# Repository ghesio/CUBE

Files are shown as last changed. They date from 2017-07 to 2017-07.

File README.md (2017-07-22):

# CUBE

## What it is

The CUBE is an IOT device with programmable 6 axis gyroscope/accelerometer, programmable LED lights, IR sensor and Bluetooth Low Energy connection.

It's based on Arduino/Genuino 101, featuring a 3D printed and laser cut shell custom designed.

The challenge of this project was to build a device with programmable functions, capable of working on different contexts, aimed at developers who can develop their own use and improvements for the CUBE.

The main idea is to use this as a music controller: based on gyroscope movements and native applications API, you can control the music you are playing; you can change the song you are listening to by rotating it, you can shuffle the music by shaking it.

It’s possible to use it as a volume controller, like a potentiometer: by rotating it with one side laying on the desk, you can increase or decrease music volume.

It will have an infrared sensor to play/stop music by swiping the hand over it.

## Features

- BLE enable
- Battery powered
- 6-Axis gyroscope
- Distance measure
- 4 LEDs acting as output/information

## Functions:

- Able to recognize rotations (clockwise and counterclockwise only, right now)
- Able to recognize swipes of the hand
- Able to recognize the heading of the cube: you can get the angle of the CUBE
- Able to recognize on which side the CUBE is on

### BOM  

- 1 x Arduino/Genuino 101
- 4 x Neopixel LEDs
- 1 x IR emitter
- 1 x IR receiver
- 1 x Switch
- 1 x 9V battery
- Lasercut and printed parts (with the material you prefer)
- Hot glue
- 20 M3 nuts
- 20 M3 1 cm screws
- Vinyl for stickers

On this repo there are also eagle files for doing an (optional) breakout board for building this project.

## BLE Reference

### Mode control, read/write
*uuid: 988dbab9-a657-45fe-80ef-9f9bed761947, read/write*

This service let choose in which mode you want to use the CUBE

0: Stand-by

1: rotation recognition

2: Swipe recognition

3: Potentiometer mode

4: Face recognition

### Rotations, read/write/notify
*uuid: 988dbab9-a657-45fe-80ef-9f9bed761948, read/write/notify*

This service keeps tracks of the rotations.
When the value is 0, no rotation happened, when it's 1 a left rotation happened, when it's 2 a right rotation happened.
Agter every rotation is necessary to write 0 before reading another.

NOTE: rotations are recognized only clockwise/counterclockwise in the direction indicated in the CUBE.

### LED, read/write
*uuid: 988dbab9-a657-45fe-80ef-9f9bed761949, read/write*

With this service it's possible to control the LEDs.

Write as value a 16-byte char array, where (the number reported here are the index of the array):
- 0: led number (possible value 3,5,6,9)
- 1-3 red component of the color (these 3 bytes represents a number between 0 and 255)
- 4-6 green component of the color (these 3 bytes represents a number between 0 and 255)
- 7-9 blue component of the color (these 3 bytes represents a number between 0 and 255)
- 10-12 white component of the color (these 3 bytes represents a number between 0 and 255)
- 13-15 brigthness (these 3 bytes represents a number between 0 and 255)

Examples:
- 3255000000000050: led #3 turned on, red with brigthness 50
- 3000000000000000: led #3 turned off
- 5000255000000255: led #5 turned on, green with max brigthness

### Swipe, read/write/notify
*uuid: 988dbab9-a657-45fe-80ef-9f9bed761950*

This service keeps track of the swipes.
When the value becomes 1, a swipe happened.
It's needed then to write 0 again in the charachteristic.

### Potenziometro, read/notify
*uuid: 988dbab9-a657-45fe-80ef-9f9bed761951*

This service advertise the CUBE angle.
It's only necessary to read the charachteristic value.
Note: there is a drifting in the PID controlling the gyroscope of about 2 degrees every half and hour.

### Riconoscimento della faccia

Based on which face the CUBE lies on, it's possible to set a different function.
Note: the active face is always the one where you can see the sticker with the number
Note: To use this mode is necessary to do a rotation before in mode 1.

### Final note

If the CUBE starts working random

## Future works / full develompent

My work on this, due to time available is over.

You can get the full story behind the develompent here: https://goo.gl/xEmkgw

Future improvements:
- Shake recognition
- Develop a real application as music controller
- Recognize all rotations

## Presentation video

https://vimeo.com/226481945

## Credits

A special thanks goes to Patrizia Marti and Matteo Sirizzotti.
A special thanks also goes to Elis Taflaj for filming and editing this video.

## License

Copyright (c) 2017 Nicola Giannelli

Permission is hereby granted, free of charge, to any person obtaining a copy of this software and associated documentation files (the "Software"), to deal in the Software without restriction, including without limitation the rights to use, copy, modify, merge, publish, distribute, sublicense, and/or sell copies of the Software, and to permit persons to whom the Software is furnished to do so, subject to the following conditions:
The above copyright notice and this permission notice shall be included in all copies or substantial portions of the Software.
THE SOFTWARE IS PROVIDED "AS IS", WITHOUT WARRANTY OF ANY KIND, EXPRESS OR IMPLIED, INCLUDING BUT NOT LIMITED TO THE WARRANTIES OF MERCHANTABILITY, FITNESS FOR A PARTICULAR PURPOSE AND NONINFRINGEMENT. IN NO EVENT SHALL THE AUTHORS OR COPYRIGHT HOLDERS BE LIABLE FOR ANY CLAIM, DAMAGES OR OTHER LIABILITY, WHETHER IN AN ACTION OF CONTRACT, TORT OR OTHERWISE, ARISING FROM, OUT OF OR IN CONNECTION WITH THE SOFTWARE OR THE USE OR OTHER DEALINGS IN THE SOFTWARE.

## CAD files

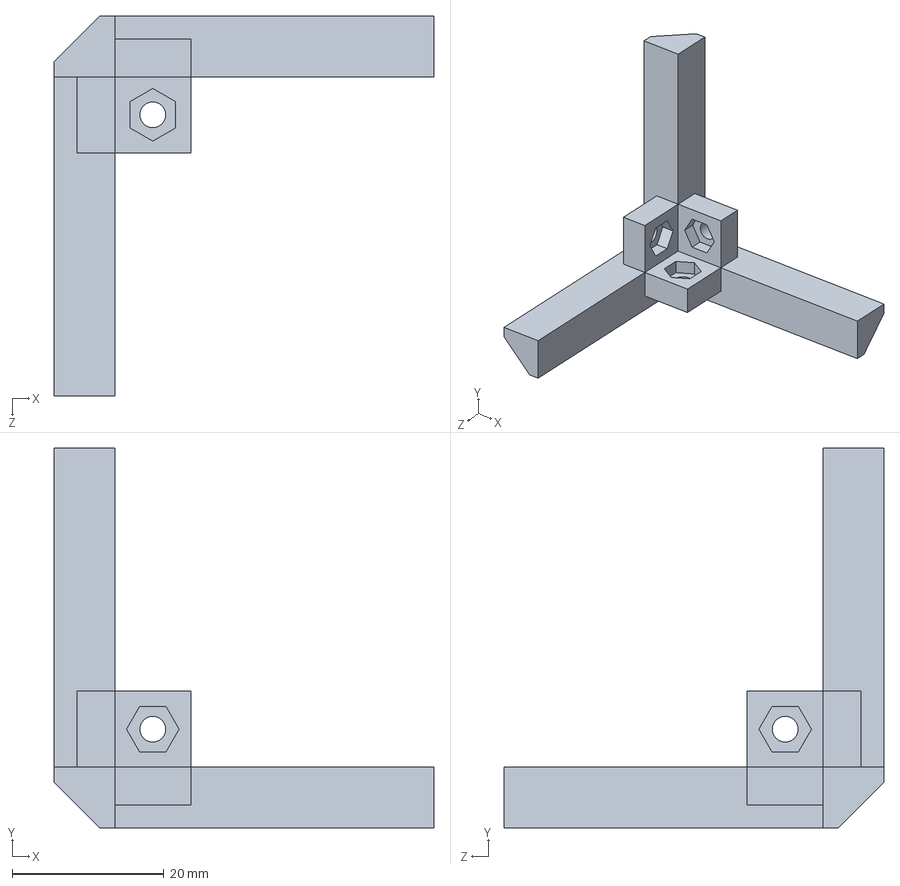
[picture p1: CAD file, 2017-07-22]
designfiles/corner.sldprt
50.0 x 50.0 x 50.0 mm

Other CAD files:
designfiles/corner.STL

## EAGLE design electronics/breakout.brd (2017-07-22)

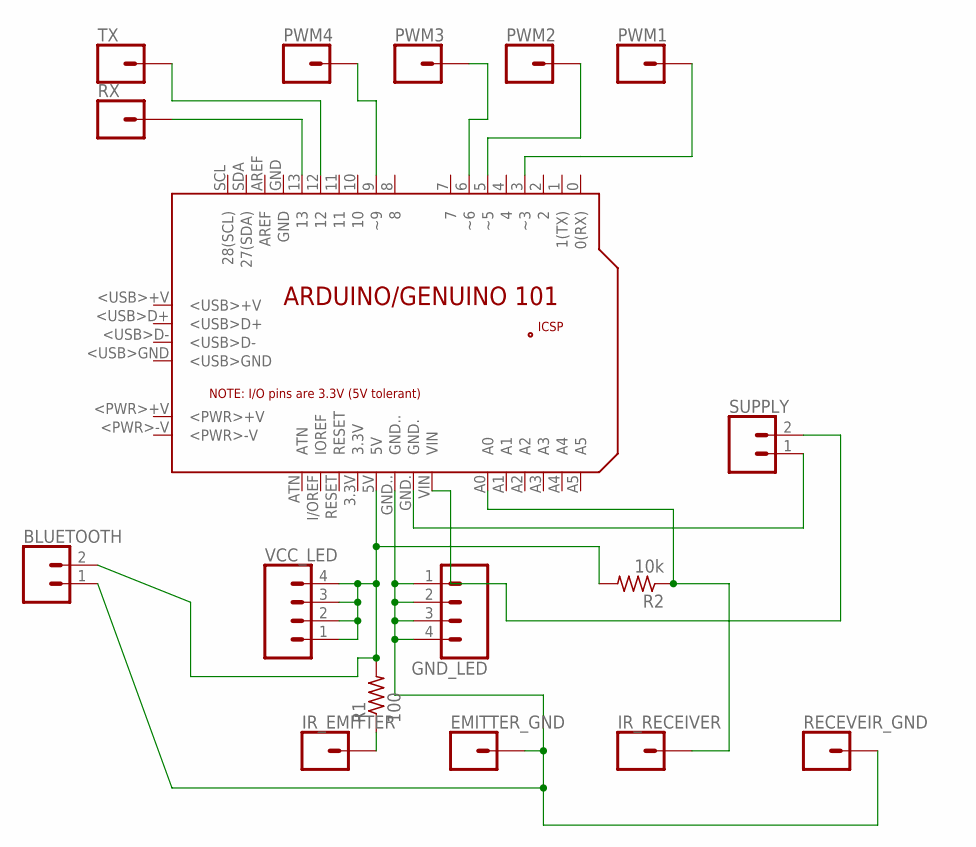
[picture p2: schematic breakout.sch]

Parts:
BLUETOOTH: CONN_02; 1X02
EMITTER_GND: CONN_01; 1X01
GND_LED: CONN_04; 1X04
IR_EMITTER: CONN_01; 1X01
IR_RECEIVER: CONN_01; 1X01
PCB1: ARDUINO_101
PWM1, PWM2, PWM3, PWM4: CONN_01; 1X01
R1: 100; R1206
R2: 10k; R1206
RECEVEIR_GND: CONN_01; 1X01
RX: CONN_01; 1X01
SUPPLY: CONN_02; 1X02
TX: CONN_01; 1X01
VCC_LED: CONN_04; 1X04

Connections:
unnamed: BLUETOOTH.2, PCB1.5V, R1.2, R2.2, VCC_LED.1, VCC_LED.2, VCC_LED.3, VCC_LED.4
unnamed: PCB1.GND., SUPPLY.1
unnamed: PCB1.3 (~3), PWM1.1
unnamed: PCB1.9 (~9), PWM4.1
unnamed: PCB1.5 (~5), PWM2.1
unnamed: PCB1.6 (~6), PWM3.1
unnamed: PCB1.VIN, SUPPLY.2
unnamed: IR_EMITTER.1, R1.1
unnamed: PCB1.13, RX.1
unnamed: IR_RECEIVER.1, PCB1.A0, R2.1
unnamed: PCB1.12, TX.1
unnamed: BLUETOOTH.1, EMITTER_GND.1, GND_LED.1, GND_LED.2, GND_LED.3, GND_LED.4, PCB1.GND.., RECEVEIR_GND.1

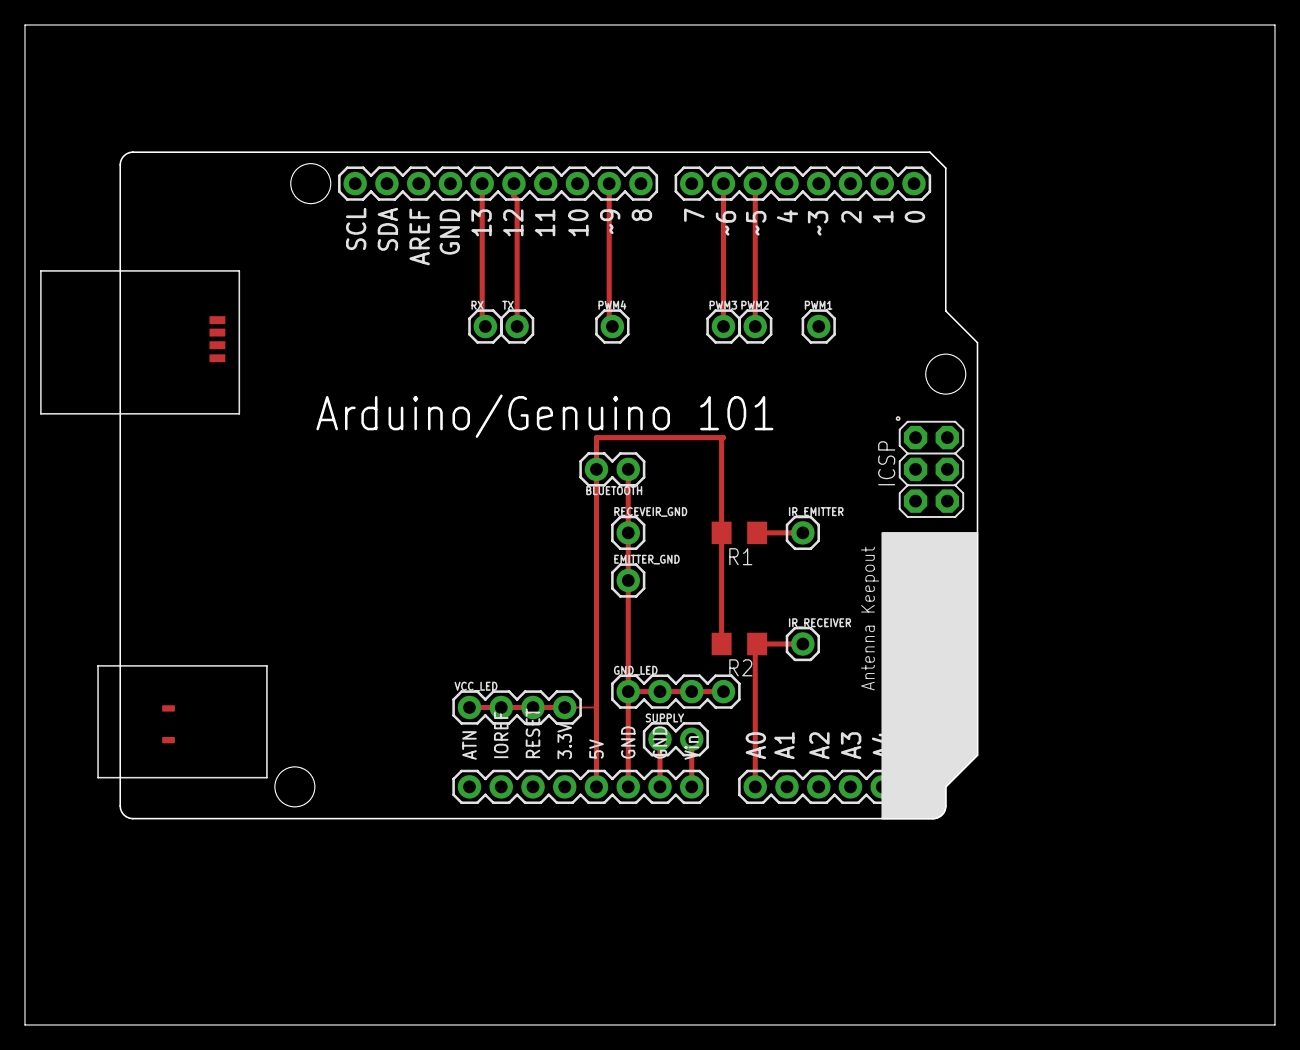
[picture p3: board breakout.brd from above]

Board: 2 copper layers, 100.0 x 80.0 mm, 17 parts (0 on the bottom side), 12 nets.

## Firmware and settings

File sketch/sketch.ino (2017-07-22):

#include "CurieIMU.h"
#include <MadgwickAHRS.h>
#include <CurieBLE.h>
#include <Adafruit_NeoPixel.h>
#define LED1 3
#define LED2 5
#define LED3 6
#define LED4 9

Adafruit_NeoPixel pixel1 = Adafruit_NeoPixel(1, LED1, NEO_GRB + NEO_KHZ800);
Adafruit_NeoPixel pixel2 = Adafruit_NeoPixel(1, LED2, NEO_GRB + NEO_KHZ800);
Adafruit_NeoPixel pixel3 = Adafruit_NeoPixel(1, LED3, NEO_GRB + NEO_KHZ800);
Adafruit_NeoPixel pixel4 = Adafruit_NeoPixel(1, LED4, NEO_GRB + NEO_KHZ800);

unsigned long previousMillis = 0;

const long interval = 500;

int ledState = LOW;

int side, oldSide;

char mode = '0';
// 0 = standby
// 1 = rotation
// 2 = swipe
// 3 = potentiometer
// 4 = face

char control = '0';

int rotation = 0;
// 1 right
// 2 left
// 0 wait

int swipe = 0;
// 1 swipe
// 0 wait

float matrix[6][3] = {
  { -1, 0, 0},
  {0, -1, 0},
  {0, 0, -1},
  {1, 0, 0},
  {0, 1, 0},
  {0, 0, 1},
};

int oldDistance, distance;

int lastOrientation = - 1, orientation; // previous orientation (for comparison)

Madgwick filter;
unsigned long microsPerReading, microsPrevious;
float accelScale, gyroScale;
float defaultAccRate;
const int ledPin =  LED_BUILTIN;
float offset;
bool check = false;

BLEPeripheral blePeripheral;

//------------------------------------------------------------------------ BLE SERVICES
BLEService modeService("988dbab9-a657-45fe-80ef-9f9bed761947");
BLEService rotationService("988dbab9-a657-45fe-80ef-9f9bed761948");
BLEService ledService("988dbab9-a657-45fe-80ef-9f9bed761949");
BLEService swipeService("988dbab9-a657-45fe-80ef-9f9bed761950");
BLEService potService("988dbab9-a657-45fe-80ef-9f9bed761951");


//------------------------------------------------------------------------ BLE CHARACTERISTICS
BLEUnsignedCharCharacteristic rotationChar("06abf104-c81d-4d93-bce5-bc6b38188ba5", BLERead | BLEWrite | BLENotify);
BLECharCharacteristic switchChar("06abf104-c81d-4d93-bce5-bc6b38188ba4", BLERead | BLEWrite);
BLECharacteristic ledChar("06abf104-c81d-4d93-bce5-bc6b38188ba3", BLERead | BLEWrite, 16);
BLEUnsignedCharCharacteristic swipeChar("06abf104-c81d-4d93-bce5-bc6b38188ba2", BLERead | BLEWrite | BLENotify);
BLECharCharacteristic potChar("06abf104-c81d-4d93-bce5-bc6b38188ba1", BLERead | BLENotify);


//------------------------------------------------------------------------ TEST

void changeColor(const char control[16]) {
  char _red[4], _green[4], _blue[4], _brightness[4], _white[4];
  int red, green, blue, brightness, white, offset;
  _red[3] = '\0';
  _green[3] = '\0';
  _blue[3] = '\0';
  _white[3] = '\0';
  _brightness[3] = '\0';
  offset = 1;
  for (int i = 0; i < 3; i++) {
    _red[i] = control[i + offset];
  }
  offset = 4;
  for (int i = 0; i < 3; i++) {
    _green[i] = control[i + offset];
  }
  offset = 7;
  for (int i = 0; i < 3; i++) {
    _blue[i] = control[i + offset];
  }
  offset = 10;
  for (int i = 0; i < 3; i++) {
    _white[i] = control[i + offset];
  }
  offset = 13;
  for (int i = 0; i < 3; i++) {
    _brightness[i] = control[i + offset];
  }
  red = atoi(_red);
  green = atoi(_green);
  blue = atoi(_blue);
  white = atoi(_white);
  brightness = atoi(_brightness);

  if (control[0] == '3') {
    pixel1.setPixelColor(0, red, green, blue, white);
    pixel1.setBrightness(brightness);
    pixel1.show();
  }
  if (control[0] == '5') {
    pixel2.setPixelColor(0, red, green, blue, white);
    pixel2.setBrightness(brightness);
    pixel2.show();
  }
  if (control[0] == '6') {
    pixel3.setPixelColor(0, red, green, blue, white);
    pixel3.setBrightness(brightness);
    pixel3.show();
  }
  if (control[0] == '9') {
    pixel4.setPixelColor(0, red, green, blue, white);
    pixel4.setBrightness(brightness);
    pixel4.show();
  }
}

void rxCharacteristicWritten(BLECentral& central, BLECharacteristic& characteristic) {
  if (characteristic.value()) {       //check if there is value
    char control[16];
    strncpy(control, (char *)characteristic.value(), 16);
    Serial.println(control);
    changeColor(control);
  }

}




//------------------------------------------------------------------------ BLE EVENT HANDLERS
void switchMode(BLECentral& central, BLECharacteristic& characteristic) {
  // central wrote new value to characteristic
  Serial.print("Characteristic event, written: ");
  if (switchChar.value() == 1) {
    Serial.println("Rotation mode");
  } else if (switchChar.value() == 2) {
    Serial.println("Swipe mode");
  }
  else if (switchChar.value() == 3) {
    Serial.println("Potentiometer mode");
  }
}

void blePeripheralConnectHandler(BLECentral& central) {
  // central connected event handler
  Serial.print("Connected event, central: ");
  Serial.println(central.address());
}

void blePeripheralDisconnectHandler(BLECentral& central) {
  // central disconnected event handler
  Serial.print("Disconnected event, central: ");
  Serial.println(central.address());
}


//------------------------------------------------------------------------ BLE SETUP
void setup() {
  pinMode(ledPin, OUTPUT);
  pinMode(A0, INPUT);
  pinMode(3, OUTPUT);
  pinMode(5, OUTPUT);
  pinMode(6, OUTPUT);
  pinMode(9, OUTPUT);
  changeColor("3000000000000020");
  changeColor("5000000000000020");
  changeColor("6000000000000020");
  changeColor("9000000000000020");
  Serial.begin(9600);
  // initialize device
  Serial.println("Initializing IMU device...");
  CurieIMU.begin();
  defaultAccRate = CurieIMU.getAccelerometerRate();

  /*
    CurieIMU.autoCalibrateAccelerometerOffset(X_AXIS, 0);
    CurieIMU.autoCalibrateAccelerometerOffset(Y_AXIS, 0);
    CurieIMU.autoCalibrateAccelerometerOffset(Z_AXIS, 1);
  */

  // Set the accelerometer range to 2G
  CurieIMU.setAccelerometerRange(2);
  CurieIMU.setGyroRate(25);
  filter.begin(25);

  // Set the gyroscope range to 250 degrees/second
  CurieIMU.setGyroRange(250);
  microsPerReading = 1000000 / 25;
  microsPrevious = micros();

  // BLE
  // set the local name peripheral advertises
  blePeripheral.setLocalName("CUBE");
  // set the UUID for the service this peripheral advertises
  blePeripheral.setAdvertisedServiceUuid(modeService.uuid());

  // add services and characteristics
  blePeripheral.addAttribute(modeService);
  blePeripheral.addAttribute(switchChar);
  blePeripheral.addAttribute(rotationService);
  blePeripheral.addAttribute(rotationChar);
  blePeripheral.addAttribute(ledService);
  blePeripheral.addAttribute(ledChar);
  blePeripheral.addAttribute(swipeService);
  blePeripheral.addAttribute(swipeChar);
  blePeripheral.addAttribute(potService);
  blePeripheral.addAttribute(potChar);

  // assign event handlers for connected, disconnected to peripheral
  blePeripheral.setEventHandler(BLEConnected, blePeripheralConnectHandler);
  blePeripheral.setEventHandler(BLEDisconnected, blePeripheralDisconnectHandler);

  // assign event handlers for characteristics
  switchChar.setEventHandler(BLEWritten, switchMode);
  ledChar.setEventHandler(BLEWritten, rxCharacteristicWritten);
  // set an initial value for the characteristics
  switchChar.setValue(0);
  rotationChar.setValue(rotation);
  swipeChar.setValue(swipe);

  // advertise the services
  blePeripheral.begin();
  Serial.println(("Bluetooth device active, waiting for connections..."));

  //lights up LED on power on
  changeColor("3000255000000050");
  changeColor("5000255000000050");
  changeColor("6000255000000050");
  changeColor("9000255000000050");
  delay(1000);
  changeColor("3000000000000000");
  changeColor("5000000000000000");
  changeColor("6000000000000000");
  changeColor("9000000000000000");



}



void loop() {
  unsigned long currentMillis = millis();

  if (switchChar.value() == 0) { // STAND BY

  }

  if (switchChar.value() == 1) { // ROTATION MODE
    orientation = - 1;   // the board's orientation
    /*
      The orientations of the board:
      1: flat, processor facing up
      2: flat, processor facing down
      3: landscape, analog pins down
      4: landscape, analog pins up
      5: portrait, USB connector up
      6: portrait, USB connector down
    */
    // read accelerometer:
    int x = CurieIMU.readAccelerometer(X_AXIS);
    int y = CurieIMU.readAccelerometer(Y_AXIS);
    int z = CurieIMU.readAccelerometer(Z_AXIS);

    // calculate the absolute values, to determine the largest
    int absX = abs(x);
    int absY = abs(y);
    int absZ = abs(z);

    if ( (absZ > absX) && (absZ > absY)) {
      // base orientation on Z
      if (z > 0) {
        orientation = 1;
      } else {
        orientation = 2;
      }
    } else if ( (absY > absX) && (absY > absZ)) {
      // base orientation on Y
      if (y > 0) {
        orientation = 3;
      } else {
        orientation = 4;
      }
    } else {
      // base orientation on X
      if (x < 0) {
        orientation = 5;
      } else {
        orientation = 6;
      }
    }

    //Serial.println(orientation);

    // current previous rotation
    //     1       3        dx
    //     1       4        sx
    //     4       1        dx
    //     4       2        sx
    //     3       2        dx
    //     3       1        sx
    //     2       4        dx
    //     2       3        sx

    // if the orientation has changed, check for rotations:
    if (orientation != lastOrientation) {
      // if for checkin rotation
      switch (orientation) {
        case 1:
          if (lastOrientation == 3) {
            rotationChar.setValue(2);
            Serial.println("DX Rotation");
            allLedOn(1);
          }
          else if (lastOrientation == 4) {
            rotationChar.setValue(1);
            Serial.println("SX Rotation");
            allLedOn(0);
          }
          break;
        case 2:
          if (lastOrientation == 4) {
            rotationChar.setValue(2);
            Serial.println("DX Rotation");
            allLedOn(1);
          }
          else if (lastOrientation == 3) {
            rotationChar.setValue(1);
            Serial.println("SX Rotation");
            allLedOn(0);
          }
          break;
        case 3:
          if (lastOrientation == 2) {
            rotationChar.setValue(2);
            Serial.println("DX Rotation");
            allLedOn(1);
          }
          else if (lastOrientation == 1) {
            rotationChar.setValue(1);
            Serial.println("SX Rotation");
            allLedOn(0);
          }
          break;
        case 4:
          if (lastOrientation == 1) {
            rotationChar.setValue(2);
            Serial.println("DX Rotation");
            allLedOn(1);
          }
          else if (lastOrientation == 2) {
            rotationChar.setValue(1);
            Serial.println("SX Rotation");
            allLedOn(0);
          }
          break;
      }
      lastOrientation = orientation;
      delay(1000);
      allLedOff();
    }
  }


  /*
    if (switchChar.value() == 1) { // ROTATION MODE
      // read accelerometer:
      CurieIMU.setAccelerometerRate(defaultAccRate);
      float x = CurieIMU.readAccelerometer(X_AXIS);
      float y = CurieIMU.readAccelerometer(Y_AXIS);
      float z = CurieIMU.readAccelerometer(Z_AXIS);
      oldSide = cubeSide(x, y, z);
      // if the orientation has changed, print out a description:
      side = cubeSide(CurieIMU.readAccelerometer(X_AXIS), CurieIMU.readAccelerometer(Y_AXIS), CurieIMU.readAccelerometer(Z_AXIS));

      if (side != oldSide) {

        if (side == 5) {
          Serial.print(side);
          Serial.print(" ");
          if (oldSide == 4) {
            Serial.println("DX rotation");
            rotationChar.setValue(2);
            changeColor("3000255000000050");
            changeColor("5000255000000050");
            changeColor("6000255000000050");
            changeColor("9000255000000050");
          }
          if (oldSide == 1) {
            Serial.println("SX rotation");
            rotationChar.setValue(1);
            changeColor("3000000255000050");
            changeColor("3000000255000050");
            changeColor("6000000255000050");
            changeColor("9000000255000050");
          }
        }

        if (side == 1) {
          Serial.print(side);
          Serial.print(" ");
          if (oldSide == 5) {
            Serial.println("DX rotation");
            rotationChar.setValue(2);
            changeColor("3000255000000050");
            changeColor("5000255000000050");
            changeColor("6000255000000050");
            changeColor("9000255000000050");
          }
          if (oldSide == 2) {
            Serial.println("SX rotation");
            rotationChar.setValue(1);
            changeColor("3000000255000050");
            changeColor("5000000255000050");
            changeColor("6000000255000050");
            changeColor("9000000255000050");
          }
        }

        if (side == 4) {
          Serial.print(side);
          Serial.print(" ");
          if (oldSide == 2) {
            Serial.println("DX rotation");
            rotationChar.setValue(2);
            changeColor("3000255000000050");
            changeColor("5000255000000050");
            changeColor("6000255000000050");
            changeColor("9000255000000050");
          }
          if (oldSide == 5) {
            Serial.println("SX rotation");
            rotationChar.setValue(1);
            changeColor("3000000255000050");
            changeColor("3000000255000050");
            changeColor("6000000255000050");
            changeColor("9000000255000050");
          }
        }

        if (side == 2) {
          Serial.print(side);
          Serial.print(" ");
          if (oldSide == 1) {
            Serial.println("DX rotation");
            rotationChar.setValue(2);
            changeColor("3000255000000050");
            changeColor("5000255000000050");
            changeColor("6000255000000050");
            changeColor("9000255000000050");
          }
          if (oldSide == 4) {
            Serial.println("SX rotation");
            rotationChar.setValue(1);
            changeColor("3000000255000050");
            changeColor("3000000255000050");
            changeColor("6000000255000050");
            changeColor("9000000255000050");
          }
        }
        //Serial.println(side);
        oldSide = side;
        delay(1000);
        changeColor("3000000000000050");
        changeColor("5000000000000050");
        changeColor("6000000000000050");
        changeColor("9000000000000050");
      }

    }
  */

  if (switchChar.value() == 2) { // SWIPE MODE
    oldDistance = analogRead(A0);
    delay(500);
    distance = analogRead(A0);
    if (distance - oldDistance > 100) {
      Serial.println("SWIPE");
      swipeChar.setValue(1);
      //
      changeColor("3255000000000050");
      changeColor("5255000000000050");
      changeColor("6255000000000050");
      changeColor("9255000000000050");
      delay(1000);
    }
    changeColor("3000000000000050");
    changeColor("5000000000000050");
    changeColor("6000000000000050");
    changeColor("9000000000000050");
    oldDistance = distance;
  }

  if (switchChar.value() == 3) { // POTENTIOMETER MODE
    CurieIMU.setAccelerometerRate(25);
    int aix, aiy, aiz;
    int gix, giy, giz;
    float ax, ay, az;
    float gx, gy, gz;
    int brigth;
    //float roll, pitch;
    float heading;
    unsigned long microsNow;

    // check if it's time to read data and update the filter
    microsNow = micros();
    if (microsNow - microsPrevious >= microsPerReading) {

      // read raw data from CurieIMU
      CurieIMU.readMotionSensor(aix, aiy, aiz, gix, giy, giz);

      // convert from raw data to gravity and degrees/second units
      ax = convertRawAcceleration(aix);
      ay = convertRawAcceleration(aiy);
      az = convertRawAcceleration(aiz);
      gx = convertRawGyro(gix);
      gy = convertRawGyro(giy);
      gz = convertRawGyro(giz);

      // update the filter, which computes orientation
      filter.updateIMU(gx, gy, gz, ax, ay, az);

      // print the heading, pitch and roll

      if (check == false) {
        CurieIMU.autoCalibrateGyroOffset();
        CurieIMU.autoCalibrateAccelerometerOffset(X_AXIS, 0);
        CurieIMU.autoCalibrateAccelerometerOffset(Y_AXIS, 0);
        CurieIMU.autoCalibrateAccelerometerOffset(Z_AXIS, 1);
        changeColor("3100100000000020");
        changeColor("5100100000000020");
        changeColor("6100100000000020");
        changeColor("9100100000000020");
        for (int i = 0; i < 10; i++) {
          offset += filter.getYaw();
        }
        offset = offset / 10;
        check = true;
      }
      heading = filter.getYaw();
      heading = heading - offset;
      heading = round(heading);
      Serial.println(heading);
      potChar.setValue(heading);
      delay(500);
      brigth = 100 + (int)heading * 8;
      Serial.println(brigth);
      pixel1.setPixelColor(0, brigth, brigth, 0, 0);
      pixel2.setPixelColor(0, brigth, brigth, 0, 0);
      pixel3.setPixelColor(0, brigth, brigth, 0, 0);
      pixel4.setPixelColor(0, brigth, brigth, 0, 0);
      pixel1.show();
      pixel2.show();
      pixel3.show();
      pixel4.show();
      // increment previous time, so we keep proper pace
      microsPrevious = microsPrevious + microsPerReading;
    }
  }

  if (switchChar.value() == 4) { // FACE MODE
    int orientation;
    /*
      The orientations of the board:
      1: flat, processor facing up
      2: flat, processor facing down
      3: landscape, analog pins down
      4: landscape, analog pins up
      5: portrait, USB connector up
      6: portrait, USB connector down
    */
    // read accelerometer:
    int x = CurieIMU.readAccelerometer(X_AXIS);
    int y = CurieIMU.readAccelerometer(Y_AXIS);
    int z = CurieIMU.readAccelerometer(Z_AXIS);

    // calculate the absolute values, to determine the largest
    int absX = abs(x);
    int absY = abs(y);
    int absZ = abs(z);

    if ( (absZ > absX) && (absZ > absY)) {
      // base orientation on Z
      if (z > 0) {
        orientation = 1;
      } else {
        orientation = 2;
      }
    } else if ( (absY > absX) && (absY > absZ)) {
      // base orientation on Y
      if (y > 0) {
        orientation = 3;
      } else {
        orientation = 4;
      }
    } else {
      // base orientation on X
      if (x < 0) {
        orientation = 5;
      } else {
        orientation = 6;
      }
    }
    Serial.println(orientation);
    pixel1.setPixelColor(0, 255, 0, 0, 0);
    pixel2.setPixelColor(0, 255, 0, 0, 0);
    pixel3.setPixelColor(0, 255, 0, 0, 0);
    pixel4.setPixelColor(0, 255, 0, 0, 0);
    pixel1.show();
    pixel2.show();
    pixel3.show();
    pixel4.show();
    delay(500 * orientation);
    pixel1.setPixelColor(0, 0, 0, 0, 0);
    pixel2.setPixelColor(0, 0, 0, 0, 0);
    pixel3.setPixelColor(0, 0, 0, 0, 0);
    pixel4.setPixelColor(0, 0, 0, 0, 0);
    pixel1.show();
    pixel2.show();
    pixel3.show();
    pixel4.show();
    delay(500 * orientation);
  }

  //DEBUG
  if (currentMillis - previousMillis >= interval) {
    previousMillis = currentMillis;
    ledState = !ledState;
    digitalWrite(ledPin, ledState);
  }
}

int cubeSide(float Ax, float Ay, float Az) {
  float largest_dot = 0;
  int closest_side = -1; // will return -1 in case of a zero A vector
  for (int side = 0; side < 6; side++) {
    float dot = (matrix[side][0] * Ax) + (matrix[side][1] * Ay) + (matrix[side][2] * Az);
    if (dot > largest_dot) {
      largest_dot = dot;
      closest_side = side;
    }
  }
  return closest_side;
}

float convertRawAcceleration(int aRaw) {
  // since we are using 2G range
  // -2g maps to a raw value of -32768
  // +2g maps to a raw value of 32767

  float a = (aRaw * 2.0) / 32768.0;
  return a;
}

float convertRawGyro(int gRaw) {
  // since we are using 250 degrees/seconds range
  // -250 maps to a raw value of -32768
  // +250 maps to a raw value of 32767

  float g = (gRaw * 250.0) / 32768.0;
  return g;
}

void allLedOn(int i) {
  if (i == 1) {
    changeColor("3255000000000255");
    changeColor("5255000000000255");
    changeColor("6255000000000255");
    changeColor("9255000000000255");
  }
  else if (i==2) {
    changeColor("3000255000000255");
    changeColor("5000255000000255");
    changeColor("6000255000000255");
    changeColor("9000255000000255");
  }
  else if (i==3){
    changeColor("3000000255000255");
    changeColor("5000000255000255");
    changeColor("6000000255000255");
    changeColor("9000000255000255");
  }
  
}

void allLedOff() {
  changeColor("3000000000000255");
  changeColor("5000000000000255");
  changeColor("6000000000000255");
  changeColor("9000000000000255");

}

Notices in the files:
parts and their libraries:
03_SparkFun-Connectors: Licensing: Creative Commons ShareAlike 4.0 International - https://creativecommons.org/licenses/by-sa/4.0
